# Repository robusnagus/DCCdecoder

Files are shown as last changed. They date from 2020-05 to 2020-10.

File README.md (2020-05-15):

## Dekoder funkcji DCC ##

Dekoder funkcji DCC z przeznaczeniem do sterowania oświetleniem wagonów.
Część sprzętowa w przygotowaniu.

### Elementy projektu ###

**funcdec_proto3208.X**  
Prototypowe oprogramowanie dla ATMega3208 (0-series). Odebrane pakiety DCC są dodatkowo dekodowane do HEX i wysyłane na port szeregowy.  
**funcdec_mk1.X**  
Oprogramowanie dla ATTiny 1614 (1-series).  

Tryby pracy: tylko DCC.  
Tryby programowania: tryb serwisowy na torze programującym.  
Adresowanie: długie (domyślnie) i krótkie.  
Wyjścia funkcyjne: zależnie od implementacji sprzętowej.

### Wersje sprzętowe ###

**Dekoder uniwersalny.**  
6 wyjść funkcyjnych z indywidualnym ściemnianiem.

### Kompilacja oprogramowania ###

Projekt MPLABX (wersja 5.35) z kompilatorem gcc dołączonym do pakietu XC8 (wersja 2.10). Użyto pakietów definicji dostarczonych wraz z MPLABX.

### Obsługa dekodera ###

| CV | Przeznaczenie | Zakres | Wart. |
|---|---|---|---|
| 1 | Adres pojazdu, krótki | | |
| 7 | Wersja dekodera, tylko do odczytu | n/d | n/d |
| 8 | Kod producenta, tylko do odczytu | n/d | n/d |
| 17 | Adres pojazdu, długi | | |
| 18 | | | |
| 29 | Konfiguracja dekodera | | |
| 33 | Mapowanie funkcji dla wyjścia A. | | |
| 34 | Mapowanie funkcji dla wyjścia A. | | |
| 45 | Deaktywacja wyjść dla kierunku ruchu: do przodu. | | |
| 47 | Deaktywacja wyjść dla kierunku ruchu: do tyłu. | | |
| 49 | Jasność dla wyjścia A. | 0-63 | 63 |

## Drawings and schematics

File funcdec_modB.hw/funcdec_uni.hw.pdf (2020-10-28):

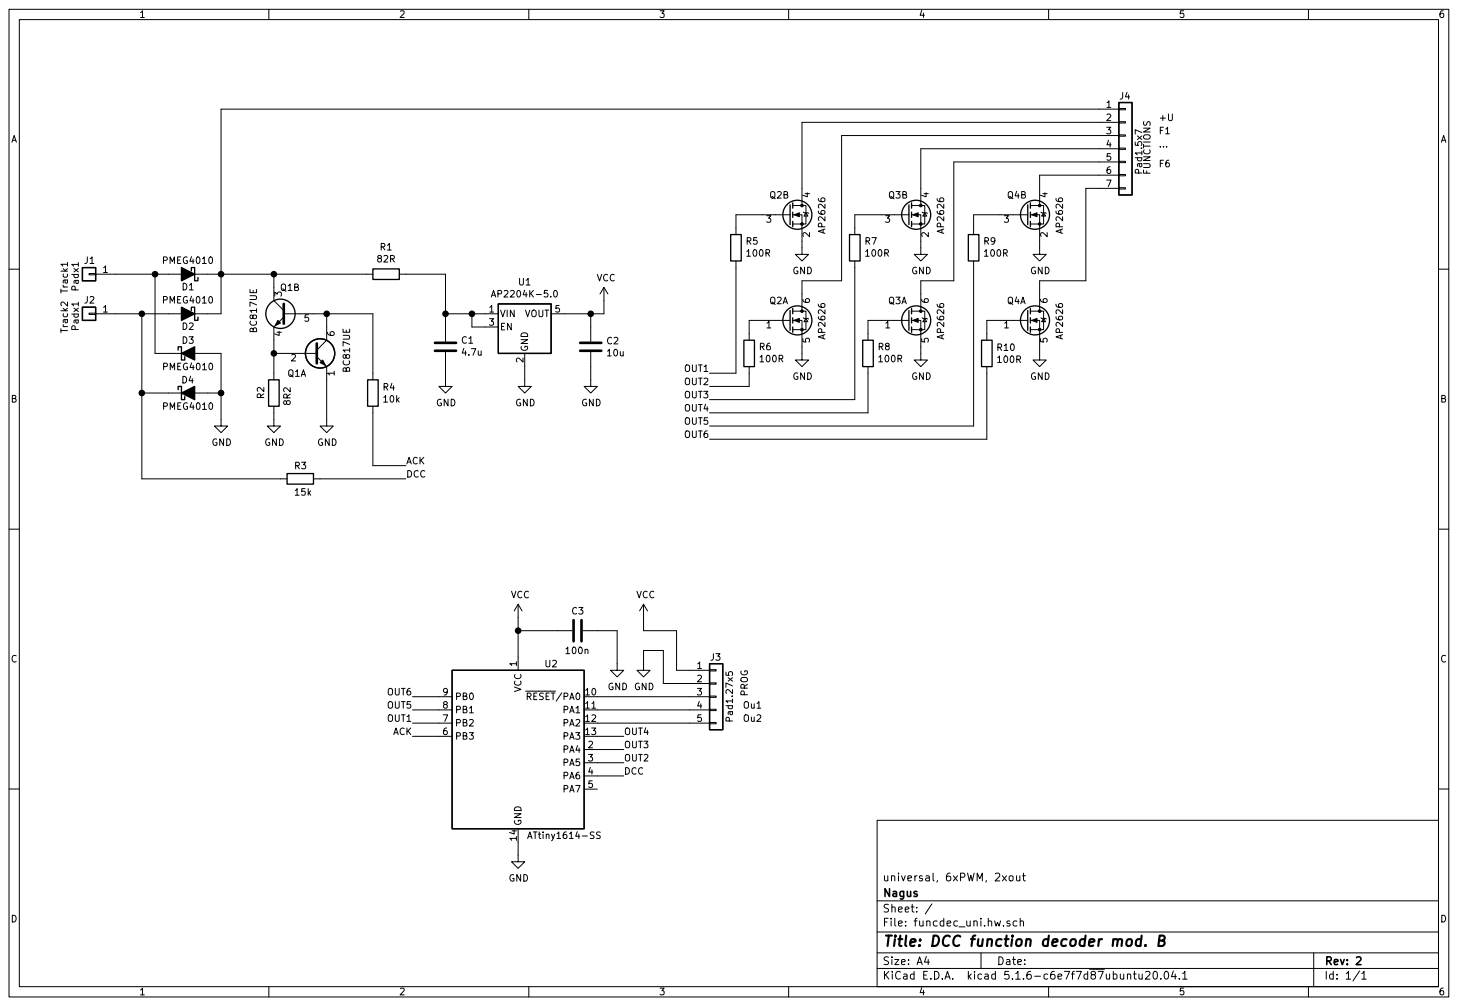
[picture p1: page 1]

File: funcdec_uni.hw.sch Sheet: / Nagus

Id: 1/1 Title: DCC function decoder mod. B

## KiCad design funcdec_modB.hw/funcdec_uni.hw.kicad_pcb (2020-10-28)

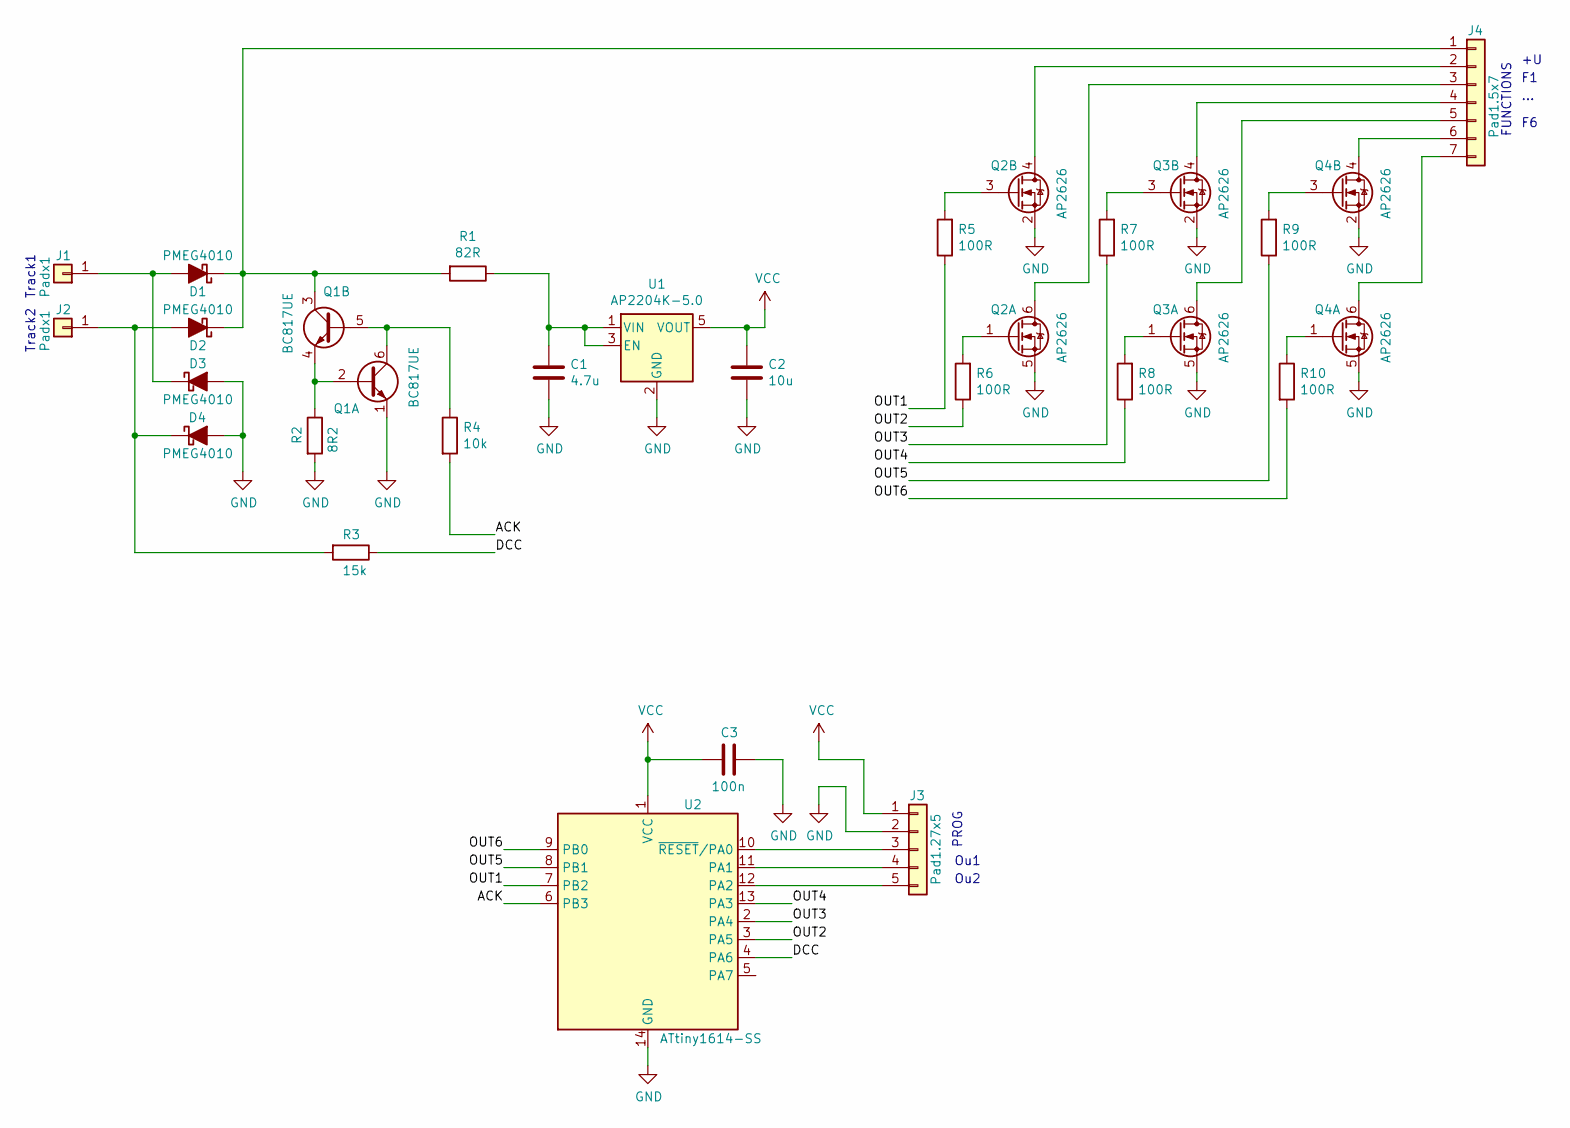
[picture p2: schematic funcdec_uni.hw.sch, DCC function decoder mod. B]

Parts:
C1: 4.7u; SMD_1206_HS
C2: 10u; SMD_1206_HS
C3: 100n; SMD_0805_HS
D1, D2, D3, D4: PMEG4010; SOD323_HS
J1, J2: Padx1; Array_1-27mm_1X1_SMD
J3: Pad1.27x5; Array_1-27mm_1X5_SMD
J4: Pad1.5x7; Array_1-50mm_1X7_SMD
Q1: BC817UE; SOT23-6_HS
Q2, Q3, Q4: AP2626; SOT23-6_HS
R1: 82R; SMD_1206_HS
R2: 8R2; SMD_0805_HS
R3: 15k; SMD_0805_HS
R4: 10k; SMD_0805_HS
R5, R6, R7, R8, R9, R10: 100R; SMD_0805_HS
U1: AP2204K-5.0; SOT23-5_HS
U2: ATtiny1614-SS; SOIC14_HS

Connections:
/ACK: R4.2, U2.6 (PB3)
/DCC: R3.1, U2.4 (PA6)
/OUT1: R5.1, U2.7 (PB2)
/OUT2: R6.1, U2.3 (PA5)
/OUT3: R7.1, U2.2 (PA4)
/OUT4: R8.1, U2.13 (PA3)
/OUT5: R9.1, U2.8 (PB1)
/OUT6: R10.2, U2.9 (PB0)
GND: C1.1, C2.2, C3.1, D3.2 (A), D4.2 (A), J3.2, Q1.1 (E1), Q2.2 (S), Q2.5 (S), Q3.2 (S), Q3.5 (S), Q4.2 (S), Q4.5 (S), R2.2, U1.2 (GND), U2.14 (GND)
unnamed: C1.2, R1.1, U1.1 (VIN), U1.3 (EN)
unnamed: D1.1 (K), D2.1 (K), J4.1, Q1.3 (C2), R1.2
unnamed: D1.2 (A), D3.1 (K), J1.1
unnamed: D2.2 (A), D4.1 (K), J2.1, R3.2
unnamed: J3.3, U2.10 (~RESET~/PA0)
unnamed: J3.4, U2.11 (PA1)
unnamed: J3.5, U2.12 (PA2)
unnamed: J4.2, Q2.4 (D)
unnamed: J4.3, Q2.6 (D)
unnamed: J4.4, Q3.4 (D)
unnamed: J4.5, Q3.6 (D)
unnamed: J4.6, Q4.4 (D)
unnamed: J4.7, Q4.6 (D)
unnamed: Q1.2 (B1), Q1.4 (E2), R2.1
unnamed: Q1.5 (B2), Q1.6 (C1), R4.1
unnamed: Q2.1 (G), R6.2
unnamed: Q2.3 (G), R5.2
unnamed: Q3.1 (G), R8.2
unnamed: Q3.3 (G), R7.2
unnamed: Q4.1 (G), R10.1
unnamed: Q4.3 (G), R9.2
VCC: C2.1, C3.2, J3.1, U1.5 (VOUT), U2.1 (VCC)

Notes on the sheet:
PROG
Track1
Track2
FUNCTIONS
...
Ou1
Ou2

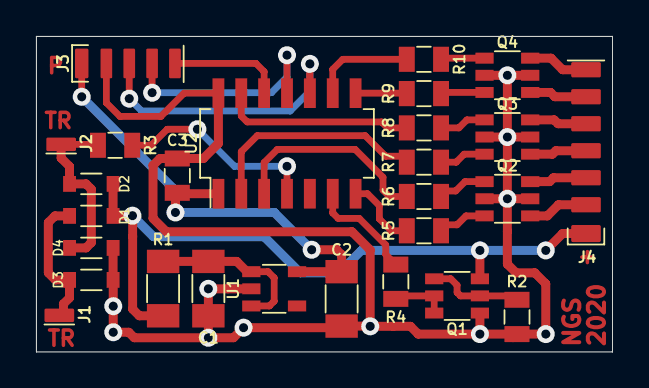
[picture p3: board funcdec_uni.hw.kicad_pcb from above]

Board: 2 copper layers, 32.0 x 17.5 mm, 27 parts (0 on the bottom side), 31 nets.

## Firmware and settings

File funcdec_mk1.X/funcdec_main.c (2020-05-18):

//
// DCC function decoder
//
// Copyright 2020 Robert Nagowski
//
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

#include "funcdec_board.h"

// ATTiny xx14
FUSES = {
	0x00, // WDTCFG{PERIOD=OFF, WINDOW=OFF}
	0x00, // BODCFG{SLEEP=DIS, ACTIVE=DIS, SAMPFREQ=1KHZ, LVL=BODLEVEL0}
	0x02, // OSCCFG{FREQSEL=20MHZ, OSCLOCK=CLEAR}
	{0x00}, // Reserved
	0x00, // TCD0CFG{CMPA=0,CMPB=0,CMPC=0,CMPD=0,CMPAEN=DIS,CMPBEN=DIS,CMPCEN=DIS,CMPDEN=DIS}
	0xF6, // SYSCFG0{EESAVE=CLEAR, RSTPINCFG=UPDI, CRCSRC=NOCRC}
	0x07, // SYSCFG1{SUT=64MS}
	0x00, // APPEND
	0x00, // BOOTEND
};

LOCKBITS = {
	0xC5, // LOCKBIT{LB=NOLOCK}
};

static uint32_t uwTick;         // zegar systemowy

extern void APP_Initialize(void);
extern void APP_TickExec(void);
extern void APP_Execute(void);

void BOARD_MCU_Init(void);
void BOARD_Clock_Init(void);
void BOARD_GPIO_Init(void);
void BOARD_TimB0_Init(void);
void BOARD_PWM_Init(void);

// inicjalizacja procesora
// param: brak
// zwrot: brak
void BOARD_MCU_Init(void)
{
	uint8_t i;
    // low power mode
    for (i = 0; i < 8; i++) {
        *((uint8_t *)&PORTA + 0x10 + i) |= (1 << PORT_PULLUPEN_bp);
        *((uint8_t *)&PORTB + 0x10 + i) |= (1 << PORT_PULLUPEN_bp);
    }
    
} // BOARD_MCU_Init

// inicjalizacja zegara
// param: brak
// zwrot: brak
void BOARD_Clock_Init(void)
{ 
    _PROTECTED_WRITE(CLKCTRL.OSC32KCTRLA, 0x00);    // RUNSTDBY disabled;
    _PROTECTED_WRITE(CLKCTRL.XOSC32KCTRLA, 0x00);   // XOSC32k disabled
    
    _PROTECTED_WRITE(CLKCTRL.OSC20MCTRLA, 0x00);    // RUNSTDBY disabled;
    _PROTECTED_WRITE(CLKCTRL.MCLKCTRLB, CLKCTRL_PDIV_2X_gc |
                                        (1 << CLKCTRL_PEN_bp));
    _PROTECTED_WRITE(CLKCTRL.MCLKCTRLA, CLKCTRL_CLKSEL_OSC20M_gc | 
                                        (0 << CLKCTRL_CLKOUT_bp));   
    _PROTECTED_WRITE(CLKCTRL.MCLKLOCK, 0x00);       // LOCKEN disabled;
    
    while (RTC.STATUS > 0) { 
	}
    RTC.CMP = 0x00;
    RTC.CNT = 0x00;
    RTC.PER = 0xFFFF;
    RTC.CLKSEL     = RTC_CLKSEL_INT32K_gc;
    RTC.DBGCTRL    = 0x00;
    RTC.INTCTRL    = 0x00;
    RTC.PITCTRLA   = RTC_PERIOD_CYC32_gc | (1 << RTC_RTCEN_bp);    
    RTC.PITDBGCTRL = 0x00;
    RTC.PITINTCTRL = (1 << RTC_PI_bp);
    RTC.CTRLA      = RTC_PRESCALER_DIV1_gc | (1 << RTC_RTCEN_bp);
    
} // BOARD_Clock_Init

// inicjalizacja portów
// param: brak
// zwrot: brak
void BOARD_GPIO_Init(void)
{      
    // OUT_ACK     PA6
    PORTA.DIRSET = (1 << PIN6_bp);
    *((uint8_t *)&PORTA + 0x16) = 0x00;
    BOARD_OUTACK_Off();
    
    // DCCIN PA1
    PORTA.DIRCLR = (1 << PIN1_bp);
    
} // BOARD_GPIO_Init

// inicjalizacja timera - odbiornik DCC
// param: brak
// zwrot: brak
void BOARD_TimB0_Init(void)
{
    EVSYS.ASYNCCH0   = EVSYS_ASYNCCH0_PORTA_PIN1_gc;
    EVSYS.ASYNCUSER0 = EVSYS_ASYNCUSER0_ASYNCCH0_gc;
    
    TCB0.CNT      = 0;
    TCB0.CCMP     = 0;
    TCB0.CTRLB    = TCB_CNTMODE_PW_gc;
    TCB0.EVCTRL   = (0 << TCB_EDGE_bp) |
                    (1 << TCB_CAPTEI_bp);
    TCB0.INTCTRL  = (1 << TCB_CAPT_bp);
    TCB0.TEMP     = 0x00;
    TCB0.INTFLAGS = (1 << TCB_CAPT_bp);
    TCB0.CTRLA    = TCB_CLKSEL_CLKDIV1_gc |
                    (1 << TCB_ENABLE_bp);   
    
} // BOARD_TimB0_Init

// inicjalizacja wyjść (ze ściemnianiem)
// param: brak
// zwrot: brak
void BOARD_PWM_Init(void)
{
    // PWM out: PA3 PA4 PA5 PB0 PB1 PB2
    PORTA.DIRSET = ((1 << PIN3_bp) | (1 << PIN4_bp) | (1 << PIN5_bp));
    *((uint8_t *)&PORTA + 0x13) = 0x00;
    *((uint8_t *)&PORTA + 0x14) = 0x00;
    *((uint8_t *)&PORTA + 0x15) = 0x00;
    PORTB.DIRSET = ((1 << PIN0_bp) | (1 << PIN1_bp) | (1 << PIN2_bp));
    *((uint8_t *)&PORTB + 0x10) = 0x00;
    *((uint8_t *)&PORTB + 0x11) = 0x00;
    *((uint8_t *)&PORTB + 0x12) = 0x00;
    
    TCA0.SPLIT.CTRLD    = (1 << TCA_SPLIT_SPLITM_bp);
    TCA0.SPLIT.HPER     = 0xFF;
    TCA0.SPLIT.LPER     = 0xFF;
    TCA0.SPLIT.HCMP0    = 0xFF;
    TCA0.SPLIT.LCMP0    = 0xFF;
    TCA0.SPLIT.HCMP1    = 0xFF;
    TCA0.SPLIT.LCMP1    = 0xFF;
    TCA0.SPLIT.HCMP2    = 0xFF;
    TCA0.SPLIT.LCMP2    = 0xFF;
    TCA0.SPLIT.HCNT     = 0x00;
    TCA0.SPLIT.LCNT     = 0x00;
    TCA0.SPLIT.CTRLB    = 0x00;     // default: OFF
    TCA0.SPLIT.CTRLA    = TCA_SPLIT_CLKSEL_DIV4_gc | (1 << TCA_SPLIT_ENABLE_bp);
 
} // BOARD_PWM_Init

// program główny
int main(void)
{
    uwTick = 0;

	BOARD_MCU_Init();
    BOARD_Clock_Init();
    BOARD_GPIO_Init();
    BOARD_TimB0_Init();
    BOARD_PWM_Init();
    
    APP_Initialize();
    // interrupt enable
	_PROTECTED_WRITE(CPUINT.CTRLA, 0x00);
	CPUINT.LVL0PRI = 0x00;
	CPUINT.LVL1VEC = 0x00;
	SYS_EnableInterrupts();
    
    static uint32_t lastTick = 0;
    // pętla główna
    while (1) {
        if (lastTick != uwTick) {
            APP_TickExec();
            lastTick = uwTick;
        }
		APP_Execute();
    }

    return 0;
    
} // main

// zegar z taktem 1ms - przerwanie
ISR(RTC_PIT_vect)
{
	RTC.PITINTFLAGS = (1 << RTC_PI_bp);
	uwTick++;
}

uint32_t SYS_GetTick(void)
{
    return uwTick;
}

// EOF funcdec_main.c

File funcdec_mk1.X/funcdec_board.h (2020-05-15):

//
// DCC function decoder
//
// Copyright 2020 Robert Nagowski
//
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

#ifndef FUNCDEC_BOARD_H
#define	FUNCDEC_BOARD_H

#include <avr/io.h>
#include <avr/interrupt.h>

#include "funcdec_config.h"

// HW config for ATTiny
// DCCIN            PA1
// OUT_ACK          PA6
// universal decoder
// 6 outputs with independent dimming
// AUXD_A AUXD_B    PB2 PA5
// AUXD_C AUXD_D    PA4 PA3
// AUXD_E AUXD_F    PB1 PB0

#define BOARD_AUXDA                 0
#define BOARD_AUXDA_On()            PORTB.OUTSET = (1 << PIN2_bp)
#define BOARD_AUXDA_Off()           PORTB.OUTCLR = (1 << PIN2_bp)
#define BOARD_AUXDA_Toggle()        PORTB.OUTTGL = (1 << PIN2_bp)
#define BOARD_AUXDB                 1
#define BOARD_AUXDB_On()            PORTA.OUTSET = (1 << PIN5_bp)
#define BOARD_AUXDB_Off()           PORTA.OUTCLR = (1 << PIN5_bp)
#define BOARD_AUXDB_Toggle()        PORTA.OUTTGL = (1 << PIN5_bp)
#define BOARD_AUXDC                 2
#define BOARD_AUXDC_On()            PORTA.OUTSET = (1 << PIN4_bp)
#define BOARD_AUXDC_Off()           PORTA.OUTCLR = (1 << PIN4_bp)
#define BOARD_AUXDC_Toggle()        PORTA.OUTTGL = (1 << PIN4_bp)
#define BOARD_AUXDD                 3
#define BOARD_AUXDD_On()            PORTA.OUTSET = (1 << PIN3_bp)
#define BOARD_AUXDD_Off()           PORTA.OUTCLR = (1 << PIN3_bp)
#define BOARD_AUXDD_Toggle()        PORTA.OUTTGL = (1 << PIN3_bp)
#define BOARD_AUXDE                 4
#define BOARD_AUXDE_On()            PORTB.OUTSET = (1 << PIN1_bp)
#define BOARD_AUXDE_Off()           PORTB.OUTCLR = (1 << PIN1_bp)
#define BOARD_AUXDE_Toggle()        PORTB.OUTTGL = (1 << PIN1_bp)
#define BOARD_AUXDF                 5
#define BOARD_AUXDF_On()            PORTB.OUTSET = (1 << PIN0_bp)
#define BOARD_AUXDF_Off()           PORTB.OUTCLR = (1 << PIN0_bp)
#define BOARD_AUXDF_Toggle()        PORTB.OUTTGL = (1 << PIN0_bp)

#define BOARD_OUTACK_On()           PORTA.OUTSET = (1 << PIN6_bp)
#define BOARD_OUTACK_Off()          PORTA.OUTCLR = (1 << PIN6_bp)
#define BOARD_OUTACK_Toggle()       PORTA.OUTTGL = (1 << PIN6_bp)

#define BOARD_DCCREC_Handler()      ISR(TCB0_INT_vect)
#define BOARD_DCCREC_SetReady()     TCB0.INTFLAGS = (1 << TCB_CAPT_bp)
#define BOARD_DCCREC_GetBitTime()   TCB0.CCMP

#define BOARD_PWM_Enable(x)         TCA0.SPLIT.CTRLB = x
#define BOARD_PWM_NONE              0x00
#define BOARD_PWMA_ENABLE           (1 << TCA_SPLIT_LCMP2EN_bp)
#define BOARD_PWMB_ENABLE           (1 << TCA_SPLIT_HCMP2EN_bp)
#define BOARD_PWMC_ENABLE           (1 << TCA_SPLIT_HCMP1EN_bp)
#define BOARD_PWMD_ENABLE           (1 << TCA_SPLIT_HCMP0EN_bp)
#define BOARD_PWME_ENABLE           (1 << TCA_SPLIT_LCMP1EN_bp)
#define BOARD_PWMF_ENABLE           (1 << TCA_SPLIT_LCMP0EN_bp)
#define BOARD_PWMA_SetDutyCycle(x)  TCA0.SPLIT.LCMP2 = x
#define BOARD_PWMB_SetDutyCycle(x)  TCA0.SPLIT.HCMP2 = x
#define BOARD_PWMC_SetDutyCycle(x)  TCA0.SPLIT.HCMP1 = x
#define BOARD_PWMD_SetDutyCycle(x)  TCA0.SPLIT.HCMP0 = x
#define BOARD_PWME_SetDutyCycle(x)  TCA0.SPLIT.LCMP1 = x
#define BOARD_PWMF_SetDutyCycle(x)  TCA0.SPLIT.LCMP0 = x

#define _PROTECTED_WRITE(reg, value)				\
    __asm__ __volatile__("out %[ccp], %[ccp_ioreg]" "\n\t"	\
                         "sts %[ioreg], %[val]"			    \
                         :					                \
                         : [ccp] "I" (_SFR_IO_ADDR(CCP)),	\
                         [ccp_ioreg] "d" ((uint8_t)CCP_IOREG_gc),	\
                         [ioreg] "n" (_SFR_MEM_ADDR(reg)),	\
                         [val] "r" ((uint8_t)value))

#define SYS_EnableInterrupts()     __asm__ __volatile__ ( "sei" ::: "memory")

#endif	// FUNCDEC_BOARD_H

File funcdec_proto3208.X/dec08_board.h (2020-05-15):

//
// DCC function decoder prototype
//
// Copyright 2020 Robert Nagowski
//
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

#ifndef DEC08_BOARD_H
#define	DEC08_BOARD_H

#include <avr/io.h>
#include <avr/interrupt.h>

#include "dec08_config.h"

// DCCIN            PA3
// OUT_ACK OUT_HB   PA2 PA7
// AUXD_A AUXD_B    PF0 PF1
// AUXD_C AUXD_D    PF2 PF3
// AUXD_E AUXD_F    PF4 PF5
// UART TX RX       PA0 PA1

#define BOARD_AUXDA                 0
#define BOARD_AUXDA_On()            PORTF.OUTCLR = (1 << PIN0_bp)
#define BOARD_AUXDA_Off()           PORTF.OUTSET = (1 << PIN0_bp)
#define BOARD_AUXDA_Toggle()        PORTF.OUTTGL = (1 << PIN0_bp)
#define BOARD_AUXDB                 1
#define BOARD_AUXDB_On()            PORTF.OUTCLR = (1 << PIN1_bp)
#define BOARD_AUXDB_Off()           PORTF.OUTSET = (1 << PIN1_bp)
#define BOARD_AUXDB_Toggle()        PORTF.OUTTGL = (1 << PIN1_bp)
#define BOARD_AUXDC                 2
#define BOARD_AUXDC_On()            PORTF.OUTCLR = (1 << PIN2_bp)
#define BOARD_AUXDC_Off()           PORTF.OUTSET = (1 << PIN2_bp)
#define BOARD_AUXDC_Toggle()        PORTF.OUTTGL = (1 << PIN2_bp)
#define BOARD_AUXDD                 3
#define BOARD_AUXDD_On()            PORTF.OUTCLR = (1 << PIN3_bp)
#define BOARD_AUXDD_Off()           PORTF.OUTSET = (1 << PIN3_bp)
#define BOARD_AUXDD_Toggle()        PORTF.OUTTGL = (1 << PIN3_bp)
#define BOARD_AUXDE                 4
#define BOARD_AUXDE_On()            PORTF.OUTCLR = (1 << PIN4_bp)
#define BOARD_AUXDE_Off()           PORTF.OUTSET = (1 << PIN4_bp)
#define BOARD_AUXDE_Toggle()        PORTF.OUTTGL = (1 << PIN4_bp)
#define BOARD_AUXDF                 5
#define BOARD_AUXDF_On()            PORTF.OUTCLR = (1 << PIN5_bp)
#define BOARD_AUXDF_Off()           PORTF.OUTSET = (1 << PIN5_bp)
#define BOARD_AUXDF_Toggle()        PORTF.OUTTGL = (1 << PIN5_bp)

#define BOARD_OUTACK_On()           PORTA.OUTSET = (1 << PIN2_bp)
#define BOARD_OUTACK_Off()          PORTA.OUTCLR = (1 << PIN2_bp)
#define BOARD_OUTACK_Toggle()       PORTA.OUTTGL = (1 << PIN2_bp)
#define BOARD_LEDHB_On()            PORTA.OUTCLR = (1 << PIN7_bp)
#define BOARD_LEDHB_Off()           PORTA.OUTSET = (1 << PIN7_bp)
#define BOARD_LEDHB_Toggle()        PORTA.OUTTGL = (1 << PIN7_bp)

#define BOARD_DCCREC_Handler()      ISR(TCB0_INT_vect)
#define BOARD_DCCREC_SetReady()     TCB0.INTFLAGS = (1 << TCB_CAPT_bp)
#define BOARD_DCCREC_GetBitTime()   TCB0.CCMP

#define BOARD_PWM_Enable(x)         TCA0.SPLIT.CTRLB = x
#define BOARD_PWM_NONE              0x00
#define BOARD_PWMA_ENABLE           (1 << TCA_SPLIT_LCMP0EN_bp)
#define BOARD_PWMB_ENABLE           (1 << TCA_SPLIT_LCMP1EN_bp)
#define BOARD_PWMC_ENABLE           (1 << TCA_SPLIT_LCMP2EN_bp)
#define BOARD_PWMD_ENABLE           (1 << TCA_SPLIT_HCMP0EN_bp)
#define BOARD_PWME_ENABLE           (1 << TCA_SPLIT_HCMP1EN_bp)
#define BOARD_PWMF_ENABLE           (1 << TCA_SPLIT_HCMP2EN_bp)
#define BOARD_PWMA_SetDutyCycle(x)  TCA0.SPLIT.LCMP0 = x
#define BOARD_PWMB_SetDutyCycle(x)  TCA0.SPLIT.LCMP1 = x
#define BOARD_PWMC_SetDutyCycle(x)  TCA0.SPLIT.LCMP2 = x
#define BOARD_PWMD_SetDutyCycle(x)  TCA0.SPLIT.HCMP0 = x
#define BOARD_PWME_SetDutyCycle(x)  TCA0.SPLIT.HCMP1 = x
#define BOARD_PWMF_SetDutyCycle(x)  TCA0.SPLIT.HCMP2 = x

#define BOARD_SERIAL_RXHandler()    ISR(USART0_RXC_vect)
#define BOARD_SERIAL_TXHandler()    ISR(USART0_DRE_vect)
#define BOARD_SERIAL_PutByte(x)     USART0.TXDATAL = x
#define BOARD_SERIAL_GetByte()      USART0.RXDATAL
#define BOARD_SERIAL_TXStart()      USART0.CTRLA |= (1 << USART_DREIE_bp)
#define BOARD_SERIAL_TXStop()       USART0.CTRLA &= ~(1 << USART_DREIE_bp)
#define BOARD_SERIAL_IsTXEmpty()    ((USART0.STATUS & USART_DREIF_bm) != 0)
#define BOARD_SERIAL_RXStart()      USART0.CTRLA |= (1 << USART_RXCIE_bp)
#define BOARD_SERIAL_RXStop()       USART0.CTRLA &= ~(1 << USART_RXCIE_bp)
#define BOARD_SERIAL_IsRXPend()     ((USART0.STATUS & USART_RXCIF_bm) != 0)

void    SERIAL_Initialize(void);
uint8_t SERIAL_SendByte(uint8_t data);
uint8_t SERIAL_SendString(char* data);
void    SERIAL_ProcessMessage(uint8_t *message);

#define _PROTECTED_WRITE(reg, value)				\
    __asm__ __volatile__("out %[ccp], %[ccp_ioreg]" "\n\t"	\
                         "sts %[ioreg], %[val]"			    \
                         :					                \
                         : [ccp] "I" (_SFR_IO_ADDR(CCP)),	\
                         [ccp_ioreg] "d" ((uint8_t)CCP_IOREG_gc),	\
                         [ioreg] "n" (_SFR_MEM_ADDR(reg)),	\
                         [val] "r" ((uint8_t)value))

#define SYS_EnableInterrupts()     __asm__ __volatile__ ( "sei" ::: "memory")

#endif	// DEC08_BOARD_H

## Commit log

2020-05-18 ack circuit correction
    [funcdec_uni.hw.kicad_pcb, funcdec_uni.hw.sch]
2020-10-28 corrections and file rename for manf
    [funcdec_uni.hw.kicad_pcb, funcdec_uni.hw.sch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]

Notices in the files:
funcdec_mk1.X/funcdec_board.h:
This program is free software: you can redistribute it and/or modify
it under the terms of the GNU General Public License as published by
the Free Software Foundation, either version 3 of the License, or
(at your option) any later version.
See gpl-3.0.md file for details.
